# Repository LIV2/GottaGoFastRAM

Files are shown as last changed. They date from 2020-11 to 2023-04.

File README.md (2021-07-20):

# GottaGoFastRAM 8MB Autoconfig Fast RAM

This is an 8MB Autoconfig Fast RAM for Amiga 500/1000/2000/CDTV based on mkl's mem68k  
It's small size allows it to be stacked on top of an ide68k board  
Rather than use the original mem68k Abel code I have written a new memory controller in Verilog

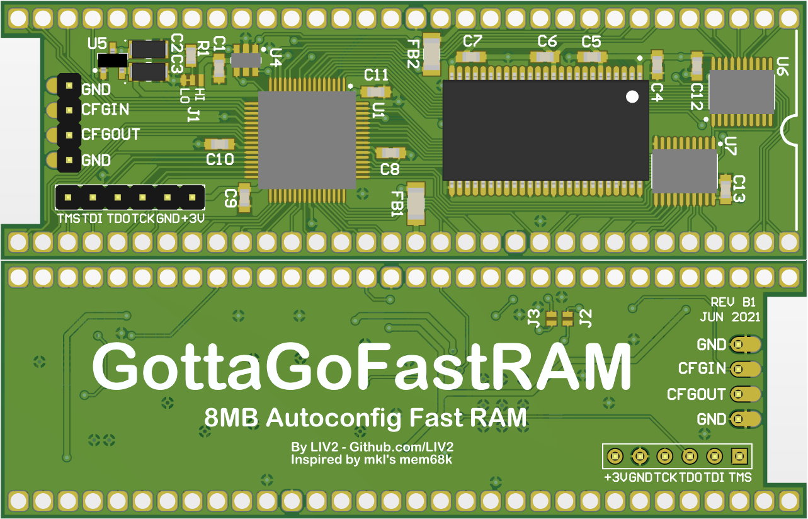
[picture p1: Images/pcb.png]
PCB

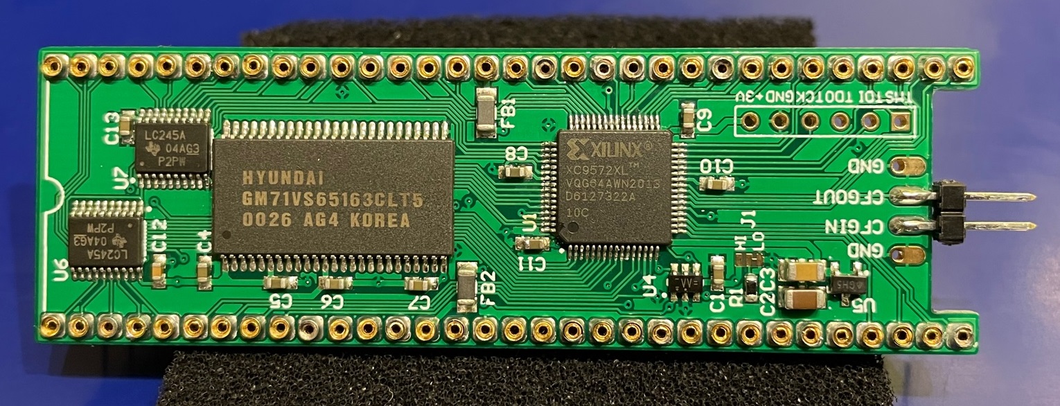
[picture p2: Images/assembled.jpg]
Assembled

## Table of contents
1. [PCB Ordering](#ordering-pcbs)
2. [Mounting Options](#mounting-options)
3. [Cfgin/out](#cfginout)
4. [Jumpers](#jumpers)
5. [CDTV](#cdtv)
6. [Timing Diagrams](#timing-diagrams)
7. [Bill of materials](#bill-of-materials)
8. [Known Issues](#known-issues)
9. [Experimental firmware](#experimental-firmware)

## Ordering PCBs
I recommend ordering the PCB with a 0.6 or 0.8mm thickness if you intend on stacking with an ide68k or mouting using a DIP socket/machined pin strips.  
If you are going to mount using the socket pins and not stacking with an ide68k I'd recommend going with the usual 1.6mm to reduce flexing.

## Mounting options

1. Can be soldered to the bottom of a machined pin socket/machined pin strips (will require some cutting of the dip socket to fit the caps/ferrites near the plastic)  
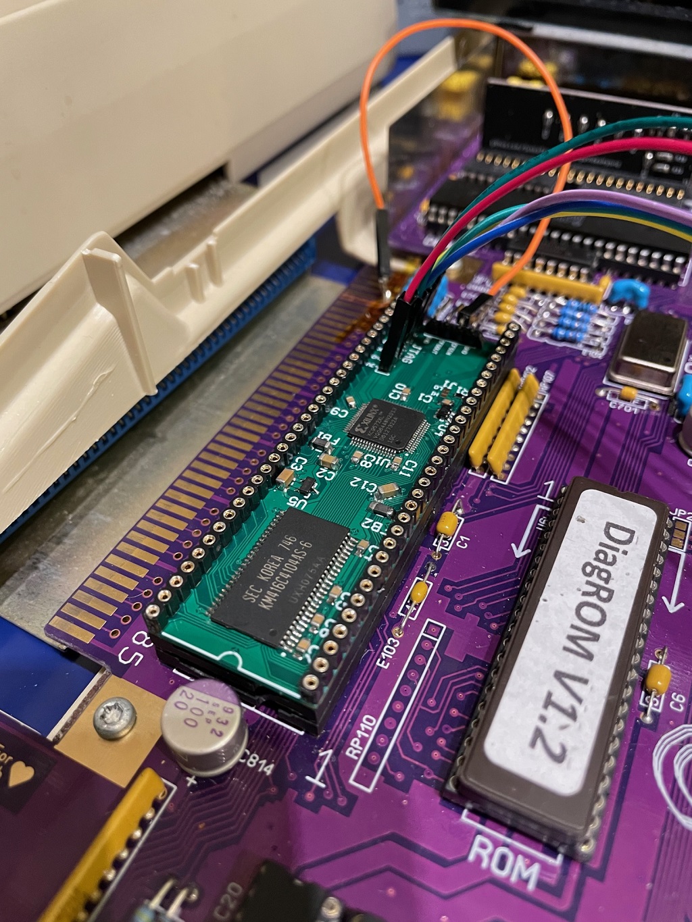
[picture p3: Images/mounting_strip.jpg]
  
2. Can be soldered to socket pins and stacked with an ide68k  
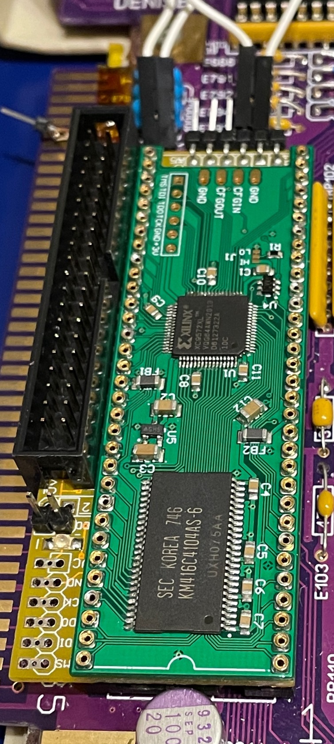
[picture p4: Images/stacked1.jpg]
  
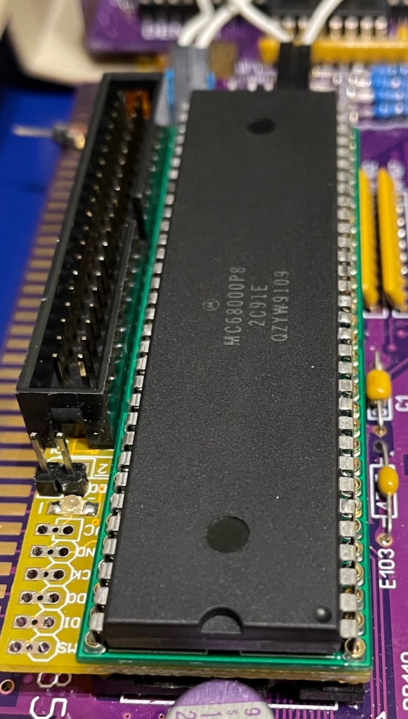
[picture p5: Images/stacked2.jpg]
  

## Cfgin/out
These pins allow you to insert the memory module into your autoconfig chain.  
If there are no other autoconfig devices in your system you can just leave these unconnected otherwise you will need to either connect CFGOut to the CFGin of the first device in your existing autoconfig chain, or connect CFGIn to the CFGOut pin of the last device in your existing autoconfig chain.  
In the Amiga 2000 you can connect CFGIN to U606 Pin 8 which will add the device to the end of the chain but __NOTE: This takes up the config signal for the leftmost slot (CN601) so do NOT install a Zorro card there__

You can also connect cfgin and cfgout with a jumper to disable the device temporarily

## Jumpers
J1: Cfgin pull up/down (You will probably want to leave this at default unless you know what you're doing)  
J2-3: Bridge these if you have not fitted the buffer U4

## CDTV
The CDTV's DMAC takes up the first autoconfig slot, so if you intend to use this with a CDTV use the CDTV specific .JED file to program the CPLD

If you have a Rev A or Rev B (not B1) board you will need to apply a [small mod for CDTV compatibility](https://github.com/LIV2/GottaGoFastRAM/issues/4/#issuecomment-868977723)

## Timing Diagrams
Read Cycle  
Write Cycle

### Bill of materials
|Component|Location|QTY|Link|Remarks|
|---|---|---|---|---|
|4Mx16 3V DRAM TSSOP - K4E641612D or GM71VS65163 |U3|1|-|eBay/Aliexpress etc.|
|XC9572XL-10VQ64C|U1|1|[Mouser](https://www.mouser.se/ProductDetail/217-C9572XL-10VQG64C)<br />[DigiKey](https://www.digikey.com/short/2f7qn38b)||
|74LVC2G17 TSSOP-6/SOT-363|U4|1|[Mouser](https://www.mouser.com/ProductDetail/771-74LVC2G17GVQ100H)<br />[DigiKey](https://www.digikey.com/short/95mn57tt) ||
|AP2210N-3.3 SOT-23|U5|1|[Mouser](https://www.mouser.com/ProductDetail/621-AP2210N-3.3TRG1)<br />[DigiKey](https://www.digikey.com/short/30rd0zn5)|Maybe can be substituted with MCP1703AT-3302E|
|74LVC245N TSSOP|U6,U7|2|[Mouser](https://www.mouser.com/ProductDetail/595-SN74LVC245APWRG4)<br />[DigiKey](https://www.digikey.com/short/pnq3wff3)|Can be substituted with SN74LVTH245 or SN74LVCR2245|
|Ferrite Bead, 1206 package|FB1, FB2|2|[Mouser](https://www.mouser.com/ProductDetail/875-MI1206K601R-10)<br />[DigiKey](https://www.digikey.com/short/n4p04ctv)|Can be substituted with 0 Ohm 1206 resistors|
|10K Resistor, 0603|R1|1|[Mouser](https://www.mouser.com/ProductDetail/603-RT0603FRD0710KL)<br />[DigiKey](https://www.digikey.com/short/nvvrt5dw)||
|0.1uF Ceramic Capacitor, 0603|C1,4-13|11|[Mouser](https://www.mouser.com/ProductDetail/80-C603C104K5RAC3121)<br />[DigiKey](https://www.digikey.com/short/f7trtfwt)||
|4.7uF Ceramic Capacitor, 1206|C2|1|[Mouser](https://www.mouser.com/ProductDetail/187-CL31B475KAHNFNE)<br />[DigiKey](https://www.digikey.com/short/d7mbf5nn)||
|10uF Ceramic Capacitor, 1206|C3|1|[Mouser](https://www.mouser.com/ProductDetail/187-CL31A106MAHNNNE)<br />[DigiKey](https://www.digikey.com/short/rqt1br0q)||
|Socket pins|Pins|64|[Aliexpress](https://www.aliexpress.com/item/32791545218.html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,searchweb201602_,searchweb201603_)|Use these if stacking with an ide68k module|
|64-Pin DIP socket - machined pin|Pins|1|[Mouser](https://www.mouser.com/ProductDetail/575-193964)|If not stacking with ide68k - pcb can be soldered to bottom of this flush with the plastic|

## Known issues
1. Rev A & B - Incorrect voltage supplied to U4 causes incompatibility with CDTV. Fixed in Rev B1 but you can [rework Rev A or B boards by following the instructions here](https://github.com/LIV2/GottaGoFastRAM/issues/4/#issuecomment-868977723)

## Experimental Firmware
* [AutoSnoop Firmware - Autoconfig after all other Z2 devices without any wires](https://github.com/LIV2/GottaGoFastRAM/tree/snoopy)

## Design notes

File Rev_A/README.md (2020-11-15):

# GottaGoFastRAM 8MB Autoconfig Fast RAM

This is an 8MB Autoconfig Fast RAM for Amiga 500/1000/2000/CDTV based on mkl's mem68k  
It's small size allows it to be stacked on top of an ide68k board  
Rather than use the original mem68k Abel code I have written a new memory controller in Verilog

Unfortunately the memory modules are hard to find, I was able to get some by scouring eBay for some 16/32MB simms and looking for ones pictured with the right ram modules - If you see a 16/32MB simm with 2/4 50-pin TSSOP modules then they're probably the right ones

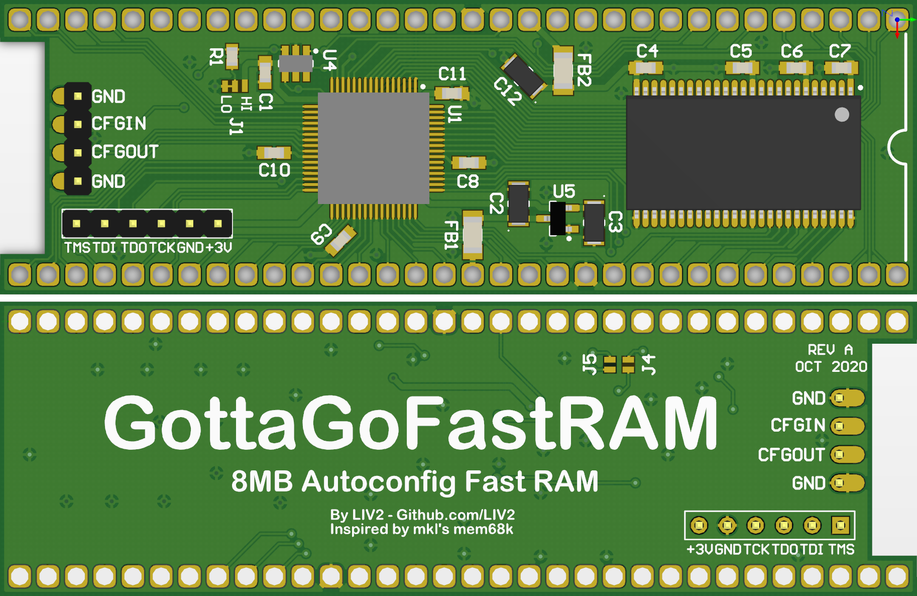
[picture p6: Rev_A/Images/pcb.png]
PCB


## PCB Ordering
I recommend ordering the PCB with a 0.6 or 0.8mm thickness if you intend on stacking with an ide68k or mouting using a DIP socket/machined pin strips.  
If you are going to mount using the socket pins and not stacking with an ide68k I'd recommend going with the usual 1.6mm to reduce flexing.

## Mounting options

1. Can be soldered to the bottom of a machined pin socket/machined pin strips (will require some cutting of the dip socket to fit the caps/ferrites near the plastic)
2. Can be soldered to socket pins and stacked with an ide68k

## Cfgin/out
These pins allow you to insert the memory module into your autoconfig chain.  
If there are no other autoconfig devices in your system you can just leave these unconnected otherwise you will need to either connect CFGOut to the CFGin of the first device in your existing autoconfig chain, or connect CFGIn to the CFGOut pin of the last device in your existing autoconfig chain.  
You can also connect cfgin and cfgout with a jumper to disable the device temporarily

## Jumpers
J1: Cfgin pull up/down (You will probably want to leave this at default unless you know what you're doing)
J2-3: Bridge these if you have not fitted the buffer U4

## CDTV
The CDTV's DMAC takes up the first autoconfig slot, so if you intend to use this with a CDTV use the CDTV specific .JED file to program the CPLD

## Timing Diagrams
Read Cycle  
Write Cycle

### Bill of materials
|Component|Location|QTY|Link|Remarks|
|---|---|---|---|---|
|4Mx16 5V DRAM - KM416C4100|U3|1|-|Look for 16MB SIMMs on eBay which show only 2 tssop package RAMs|
|XC9572XL-10VQ64C|U1|1|[Mouser](https://www.mouser.se/ProductDetail/217-C9572XL-10VQG64C)||
|74LVC2G17|U4|1|[Mouser](https://www.mouser.com/ProductDetail/771-74LVC2G17GVQ100H)||
|AP2210N-3.3|U5|1|[Mouser](https://www.mouser.com/ProductDetail/621-AP2210N-3.3TRG1)||
|Ferrite Bead, 1206 package|FB1, FB2|2|[Mouser](https://www.mouser.com/ProductDetail/875-MI1206K601R-10)||
|0.1uF Ceramic Capacitor, 0603|C1,4-11|9|[Mouser](https://www.mouser.com/ProductDetail/80-C603C104K5RAC3121)||
|4.7uF Ceramic Capacitor, 1206|C2,C12|2|[Mouser](https://www.mouser.com/ProductDetail/791-1206X475K160CT)||
|10uF Ceramic Capacitor, 1206|C3|1|[Mouser](https://www.mouser.com/ProductDetail/80-C1206C106K4R)||
|Socket pins|Pins|64|[Aliexpress](https://www.aliexpress.com/item/32791545218.html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,searchweb201602_,searchweb201603_)|Use these if stacking with an ide68k module|
|64-Pin DIP socket - machined pin|Pins|1|[Mouser](https://www.mouser.com/ProductDetail/575-193964)|If not stacking with ide68k - pcb can be soldered to bottom of this flush with the plastic|

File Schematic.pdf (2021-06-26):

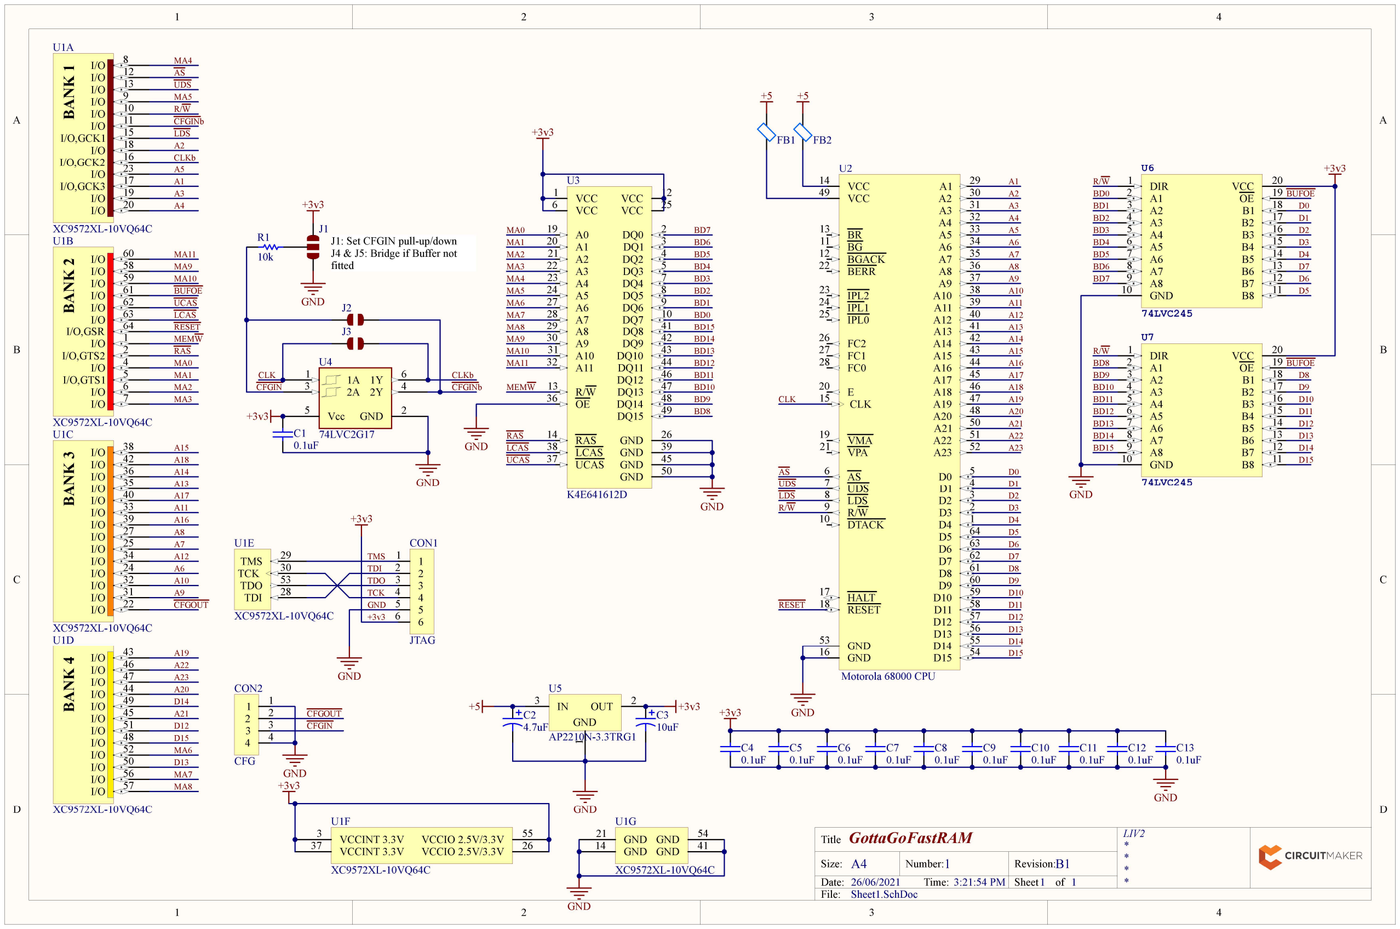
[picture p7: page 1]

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
LIV2
*
*
*
1 *

## GottaGoFastRAM

### 1 B1

26/06/2021 | 3:21:54 PM
Sheet1.SchDoc

Title

Size: | Number:
Date:
File:

Revision:
Time: | Sheet | of

A4

VCC 1

DQ0 | 2
DQ1 | 3
DQ2 | 4
DQ3 | 5

VCC 6

DQ4 | 7
DQ5 | 8
DQ6 | 9
DQ7 | 10
VCC | 12

R/W 13

RAS 14

A0 19
A1 20
A2 21
A3 22
A4 23
A5 24
VCC | 25
GND | 26

A6 27
A7 28
A8 29
A9 30
A10 31
A11 32

OE 36

UCAS 37 | LCAS 38 | GND | 39
DQ8 | 41
DQ9 | 42
DQ10 | 43
DQ11 | 44
GND | 45
DQ12 | 46
DQ13 | 47
DQ14 | 48
DQ15 | 49
GND | 50

U3

K4E641612D

D4 | 1
D3 | 2
D2 | 3
D1 | 4
D0 | 5 AS 6
UDS 7
LDS 8
R/W 9
DTACK 10

BG 11
BGACK 12

BR 13

VCC 14

CLK 15

GND 16

HALT 17
RESET 18

VMA 19

E

20

VPA 21

BERR 22

IPL2 23
IPL1 24
IPL0 25

FC2 26
FC1 27
FC0 28
A1 | 29
A2 | 30
A3 | 31
A4 | 32
A5 | 33
A6 | 34
A7 | 35
A8 | 36
A9 | 37
A10 | 38
A11 | 39
A12 | 40
A13 | 41
A14 | 42
A15 | 43
A16 | 44
A17 | 45
A18 | 46
A19 | 47
A20 | 48

VCC 49

A21 | 50
A22 | 51
A23 | 52

GND 53

D15 | 54 D14 | 55 D13 | 56 D12 | 57 D11 | 58 D10 | 59 D9 | 60 D8 | 61 D7 | 62 D6 | 63 D5 | 64

U2

Motorola 68000 CPU

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
RESET

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
MA10
MA11

+3v3

GND

MEMW

RAS
LCAS
UCAS BANK ¹I/O | 8
I/O | 12
I/O | 13
I/O | 9
I/O | 10
I/O | 11
I/O,GCK1 | 15
I/O | 18
I/O,GCK2 | 16
I/O | 23
I/O,GCK3 | 17
I/O | 19
I/O | 20

U1A

XC9572XL-10VQ64C BANK ²I/O | 60
I/O | 58
I/O | 59
I/O | 61
I/O | 62
I/O | 63
I/O,GSR | 64
I/O | 1
I/O,GTS2 | 2
I/O | 4
I/O,GTS1 | 5
I/O | 6
I/O | 7

U1B

XC9572XL-10VQ64C BANK ³I/O | 38
I/O | 42
I/O | 36
I/O | 35
I/O | 40
I/O | 33
I/O | 39
I/O | 27
I/O | 25
I/O | 34
I/O | 24
I/O | 32
I/O | 31
I/O | 22

U1C

XC9572XL-10VQ64C BANK ⁴I/O | 43
I/O | 46
I/O | 47
I/O | 44
I/O | 49
I/O | 45
I/O | 51
I/O | 48
I/O | 52
I/O | 50
I/O | 56
I/O | 57

U1D

XC9572XL-10VQ64C

TCK | | 30
TDI | 28 TDO | 53
TMS | | 29

U1E

XC9572XL-10VQ64C

VCCINT 3.3V 3

VCCINT 3.3V 37 | VCCIO 2.5V/3.3V | 26 VCCIO 2.5V/3.3V | 55

U1F

XC9572XL-10VQ64C

GND 14 | GND 21
GND | 41 GND | 54

U1G

XC9572XL-10VQ64C

MEMW
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
MA10

MA11

R/W
CFGINb

AS
UDS

LDS

CLKb

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
BUFOE
UCAS
LCAS
RESET

CFGOUT

+3v3

GND

IN 3 | 1
OUT | 2

GND

U5

AP2210N-3.3TRG1

GND

+5 | +3v3

+5

C2
4.7uF

C3
10uF
C4
0.1uF

C5
0.1uF

C6
0.1uF

C7
0.1uF

C8
0.1uF

C9
0.1uF

C10
0.1uF

C11
0.1uF

GND

+3v3 1

1
2

2
3

3
4

4

CON2

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
CON1

JTAG

GND

+3v3

TMS
TDI
TDO
TCK
GND
+3v3

GND

CFGIN

CFGOUT

1A 1

GND 2

2A 3

2Y 4

Vcc 5

1Y 6

U4

C1 74LVC2G17
0.1uF

GND

CLK | CLKb
CFGIN | CFGINb

J1

GND

R1
10k

FB1 FB2

J2

J3

J1: Set CFGIN pull-up/down J4 & J5: Bridge if Buffer not fitted

GND

R/W

R/W

BUFOE

BUFOE

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
BD10
BD11
BD12
BD13
BD14
BD15

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
BD10

BD11

BD12

BD13

BD14

BD15

DIR 1
A1 2
A2 3
A3 4
A4 5
A5 6
A6 7
A7 8
A8 9
GND 10 | B8 | 11 B7 | 12 B6 | 13 B5 | 14 B4 | 15 B3 | 16 B2 | 17 B1 | 18 OE | 19 VCC | 20

U6

74LVC245

DIR 1
A1 2
A2 3
A3 4
A4 5
A5 6
A6 7
A7 8
A8 9
GND 10 | B8 | 11 B7 | 12 B6 | 13 B5 | 14 B4 | 15 B3 | 16 B2 | 17 B1 | 18 OE | 19 VCC | 20

U7

74LVC245
GND

+3v3

C12
0.1uF

C13
0.1uF

+3v3

+3v3

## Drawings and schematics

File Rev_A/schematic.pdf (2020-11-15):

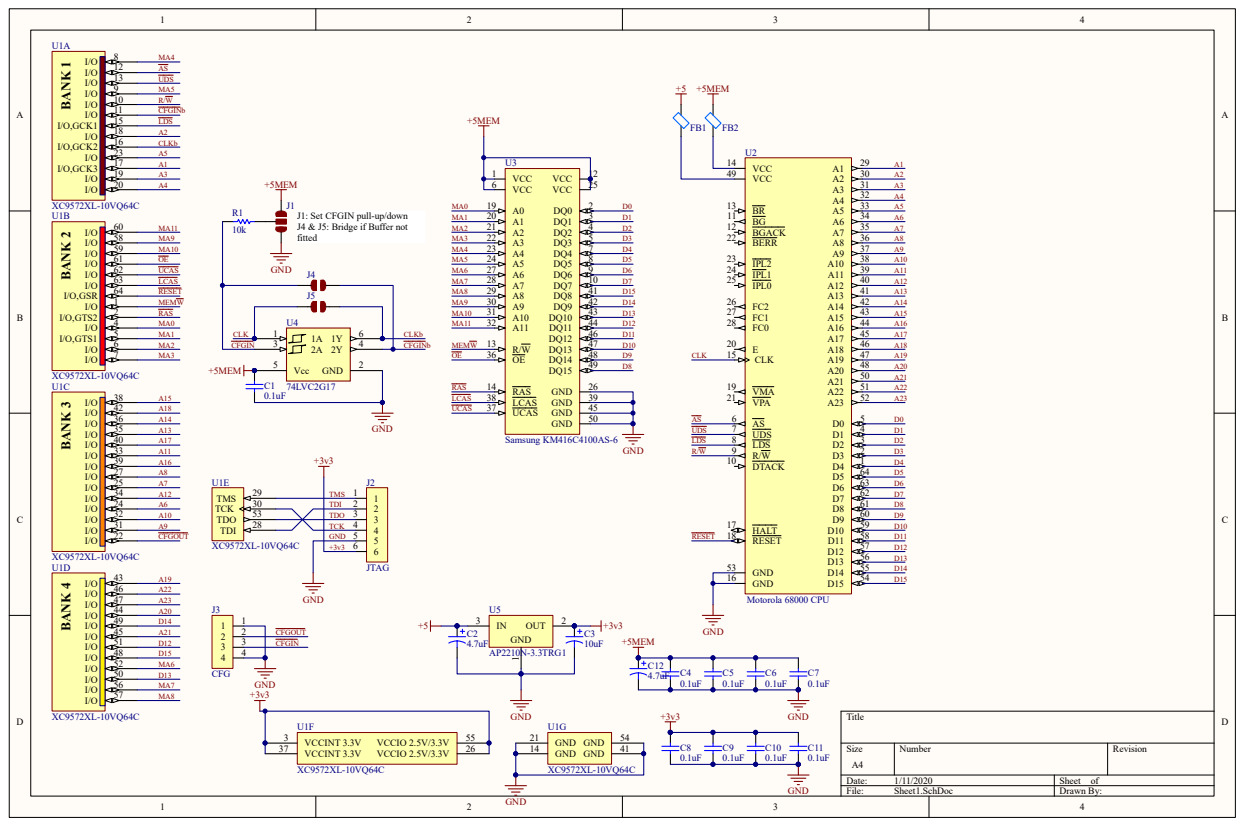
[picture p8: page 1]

J1: Set CFGIN pull-up/down
J4 & J5: Bridge if Buffer not
fitted

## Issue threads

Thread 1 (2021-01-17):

Magenta error color?!?

pazuzu72, 2021-01-17:
I made this expansion for my Amiga 1000 and I must say it works perfectly without any problems. The only weird thing I noticed is that on power up, before the kickstart screen, the color is magenta (?) where it was gray before.

LIV2, 2021-01-18:
Hi @pazuzu72

Weird! I think maybe it's because I made a mistake that caused the buffers to enable during reset which might have been causing your magenta screen.

I've attached an updated .jed file which should correct this mistake and hopefully fix your magenta screen: [gottagofast.zip](https://github.com/LIV2/GottaGoFastRAM/files/5827831/gottagofast.zip)

I hope that fixes it!

pazuzu72, 2021-01-18:
Thanks. I'll try it later. I will post the result of the update.

LIV2, 2021-02-11:
@pazuzu72 Did this solve your issue?

pazuzu72, 2021-02-11:
Unfortunately I didn't have time due to work. I hope this weekend to succeed. It will be my pleasure to post the result.

pazuzu72, 2021-02-12:
All right. The magenta is gone !! Thanks so much :-)

LIV2, 2021-02-13:
Awesome, glad I could help!

Closed 2021-02-13.

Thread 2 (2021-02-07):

schematic pdf

kipper2k, 2021-02-07:
Hi,  Great design, i like the 1x8MB ram chip.  I have made a A500 IDE board with CF header and would like to add this fastmem design to it, Do you have  a schematic pdf available for sharing or eagle cad files ?

Thanks.  Brian.

LIV2, 2021-02-07:
Hi Brian,

Thanks, this board was designed with Altium CircuitMaker but the schematics are available here: https://github.com/LIV2/GottaGoFastRAM/blob/master/Schematic.pdf

Do you have a link to your project? It sounds good I'd love to get my hands on one when it is released :)

Closed 2021-03-18.

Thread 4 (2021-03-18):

Doesn't work in CDTV

LIV2, 2021-03-18:
Need to acquire a CDTV to find out why

nobodyisinocent, 2021-06-02:
Hello,
I confirm that the jed file for the CDTV doesn't work.
You said that you don't own a CDTV, but if you want I can test new jed files if you want since I have a CDTV and a GottaGOFastRAM ! No problem for me.
Kind regards,
Franck

LIV2, 2021-06-03:
Hi @nobodyisinocent
That would be great! I will try to have an educated guess as to what the problem could be and return with some JED files to test

nobodyisinocent, 2021-06-03:
Hi Liv !
Great news ! I'll wait for your new JED to make tests !
Perhaps you could also look at the 4MB SRAM of the TK30 designed by Mattze from a1k.org.
He had made a specific JED file for his board. It's not the same design but perhaps that could help you ?
Kind regards,
Franck

LIV2, 2021-06-03:
I've tweaked a few things based on learnings from the GottaGoFastRAM2000 board which I am hoping will help, Can you please try out the attached jed file when you have the time and let me know? Thanks for the idea I will check out that project too
[ggfcdtvtest1.zip](https://github.com/LIV2/GottaGoFastRAM/files/6590549/ggfcdtvtest1.zip)

nobodyisinocent, 2021-06-03:
Hi !

New jed file injected into the XC and tested. Actually I obtain the same issue.

I realized I didn't explain what's happening why the CDTV is switched on.
1- The CDTV displays a black screen. The CD-ROM is initialized during this step,
2- A a faded yellow screen is displayed just after during a few seconds,
3- A reset is automatically done,
4- And we go back to the step 1.

I tested also with a floppy drive connected to see if I could hear the click of the drive. Nothing !

Kind regards,
Franck

LIV2, 2021-06-03:
Strange...

Does your board work in an A500?

If possible can remove the board and boot up Sysinfo and see how many boards are listed under the "Boards" option?

LIV2, 2021-06-03:
Also can you try the attached firmware? this one doesn't use autoconfig it just forces the memory to map so it can be tested with AmigaTestKit by choosing the option to detect memory, you should be able to detect 8MB and then test it all which will tell us if the part that is broken is related to autoconfig or related to the memory control

[gottagofastnoautoconf.zip](https://github.com/LIV2/GottaGoFastRAM/files/6593253/gottagofastnoautoconf.zip)

LIV2, 2021-06-03:
And another autoconfig one to test when you get a second please :)

[gottagofastcdtvtest3.zip](https://github.com/LIV2/GottaGoFastRAM/files/6593328/gottagofastcdtvtest3.zip)

nobodyisinocent, 2021-06-03:
Initially, the board worked onto the A500. I'm going to inject the firmware for the A500 if everything is good.
After, I'll test the two firmwares you sent today.

One question, For the CDTV, is there another signal which is needed to be picked up ?
I read something about CFGOut and CFGin. One of them is needed since there is an autoconfig device on the CDTV (DMAC) ?

LIV2, 2021-06-04:
In the CDTV the dmac's cfgin is tied to ground but it does have a CFGOUT by the looks of it but this doesn't appear to be easily accessible - only connected to the diagnostic port

The firmwares for various CDTV fast ram boards (incl my CDTV fw) work around this by watching the bus and wait until after they see the DMAC being configured before they respond to autoconfig requests.

I have tested that this part works with an A500 & A590 setup which has the same DMAC

nobodyisinocent, 2021-06-04:
Hi !

Thanks for the information about the GFG signals.

About my RAM board, I have put the A500 firmware into the cpld. On the A500, I obtain a red screen.
The GottaGoFastRAM is installed onto a IDE68K. So, I have removed the /OVR and /INT2 connector. And in this configuration, the A500 displayed directly the early boot menu on the device menu. The RAM is shown as defective. I don't understand why since this board worked fine before onto my A500.
I put the no-auto-config firmware, and the A500 booted fine onto the IDE68K.

Anyway, I had an another IDE68K + GottaGoFastRAM onto this A500. So, I have injected the first firmware you sent me to test if the result would be the same. And yes, the result is the same with yellow screen.
So, I have injected again the A500 firmware to verify the integrity of the board ram. And yes, it always works perfectly.

I have finally injected the no-Auto-config firmware to test into the cpld. Tested onto my CDTV, it boots perfectly onto the CF card of the IDE68K. This evening, I'll test to add the memory manually with the "addmen" command line.

And after, I'll test the third firmware you've sent !

LIV2, 2021-06-04:
Hmm the "Defective" screen usually means that kickstart did a memory test and found the ram to be faulty - perhaps a bad solder joint or something? It should work fine with the IDE68K I have a few here stacked with this ram board.

Better than addmem is booting [AmigaTestKit](https://github.com/keirf/Amiga-Stuff/releases) if you have a Gotek or something - this allows you to autodetect memory and test it.

Thanks so much for your help!

nobodyisinocent, 2021-06-04:
Yes, it worked before. But yes, I suspect faulty ram. I'll check the soldering.

Yes, I have downloaded AmigaTestKit also, and I'll used it. :-)

No problem. It's a pleasure, I like your little board !

nobodyisinocent, 2021-06-05:
Hi,

I have tried to test the RAM on my CDTV. AmigaTest Kit refused to run. The menu wasn't available...
I tried onto an A500+, and there, it has run fine. The 8MB were found.

So, I have tested again onto my CDTV with the CDROM part disabled thanks to the JP15 jumper which have to be opened in that case. Like that, I obtain a pure A500. In this configuration, AmigaTestKit run fine, but the test is not successful. Only 3.5MB are found as you can see on the picture.
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

Presently, My CDTV is equipped with the 2.30 Extended ROMs. I'll test with the original ones, but I have to take a look at the jumpers. I'm sure I have modified one of them to use the 2.30 ROMs, but I don't remember which one !

nobodyisinocent, 2021-06-05:
For information, if I use AddMem 200000 9FFFFF, the command line returns an error which says that only a part of memory is found and the Fast RAM is not activated.
I'll note the exact error message.

LIV2, 2021-06-06:
Well that is very strange, I get the feeling there is some problem with the design. perhaps the buffers don't work well with the CDTV for some reason (noise immunity or something?)

I've bought a CDTV on eBay now so I can poke around with my oscilloscope etc, thanks so much for your help I'll keep this thread updated with my findings

nobodyisinocent, 2021-06-06:
Hi,

Great news ! Will be easier to find the problem.
For information, I have tested the 68030/4MB accelerator board from Matze.
The memory part of the accelerator board uses the A500 jed.
For that, I have disabled the CD-ROM part (with jumper JP15 opened). Like that, no DMAC initialization.
And the board run fine as shown into the pictures below.
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

nobodyisinocent, 2021-06-06:
Okay ! Thanks a lot for your great work ! :-)

LIV2, 2021-06-26:
Hi @nobodyisinocent

I received my CDTV earlier this week and have figured out the problem.
I made a mistake in the design by supplying the clock buffer with 5V instead of 3.3V which causes it to have the wrong threshold voltage for the clock when installed in a CDTV (but works fine on other amigas for some reason)

Yellow is the clock from the CDTV, blue is the buffered clock signal. ignore the difference between before/after for the yellow trace the amplitude is different because I didn't have a solid probe connection - only the buffered trace is interesting

## Before fix: the resulting clock output has too narrow a pulse that is late which causes the ram controller to not function correctly and misbehave
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

## After fix: nice square clock
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

## The fix:
You can fix this on a Rev B board in one of two ways:
1. Cut the relevant power trace at the right place and solder a jumper wire between the positive sides of C1 and C3 (recommended)
2. Remove U4 and solder the two jumpers closed on the bottom of the board

The buffer serves a useful purpose of cleaning the clock signal if there is noise or too slow rise time so I recommend doing option 1 as follows:
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

Make sure to reflash the CDTV specific firmware from the master branch rather than the testing ones I sent previously.

I'll update the documentation with this fix and also update the PCB design to fix this problem

nobodyisinocent, 2021-06-26:
Hi LIV !

It's a great news ! Perfect job. +1:
I'm going to make the mod onto my GottaGoFastRAM.
Mine is directly soldered onto an IDE68k board. I'll used the first recommended way.
I took a look at the schematic. For my configuration, if I cut the track between the via and C1 onto the top layer, that will be the same since HI position of J1 isn't closed. And as shown in your picture, I'll solder the wire between C3 & C1.

Fantastic ! My CDTV will have a 8MB board and an IDE port ! And it's thanks to you ! :-)
I'll say you as soon as it will be done.
Have a nice week-end.

LIV2, 2021-06-29:
Fantastic! Thanks so much for your help :)

MirekBie, 2022-12-20:
Hello. Can you tell me how to update the firmware for cdtv in GottaGoFastRam. what software and programmer to use?

LIV2, 2022-12-21:
@MirekBie you can program using a Raspberry Pi following the instructions here: https://linuxjedi.co.uk/2021/11/25/revisiting-xilinx-jtag-programming-from-a-raspberry-pi/ but you would replace FLASH_KICKSTART.jed at the xc3sprog command with the filename of the .jed you wish to program

Closed 2021-06-29.

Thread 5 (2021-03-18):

kipper2k cfide board variation

kipper2k, 2021-03-18:

kipper2k, 2021-03-18:
Hi, sorry i missed respoding in the other thread, i just tested my a508ide board, IDE works, there are quite a few jumpers on the underside where i forgot needed cpu signals, i will test the 8MB ram later tomorrow and if all good i will submit what should be final version. once good i will release

Closed 2023-10-19.

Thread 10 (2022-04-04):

Combination with A570 and "2MB RAM for A570"

StefanKrupop, 2022-04-04:
Dear LIV2,

thank you for this project! I built one and it seems to be working fine so far (just finished it).

I am using an A570 (together with a [Vector Falcon 570](http://amiga.resource.cx/expde/falcon570)) and tied CFGIN of the GottaGoFastRAM to Pin 11 on the A500 expansion connector, so it will get asserted after the DMAC in the A570 is configured. Seems to be ok, I see 2 MB Chip and 8 MB Fast.

However, I previously had a [2MB RAM for A570](http://amiga.resource.cx/expde/2mb570) expansion in the A570 as well, providing 2 MB of Fast RAM.
I now had to remove it to get the full 8 MB provided by the GottaGoFastRAM. With it installed the Amiga sees just 6 MB of Fast RAM.

I wonder whether it would be possible to use both expansions simultaneously, giving a total of 10 MB Fast RAM? The 2 MB RAM in the A570 seem to be mapped to 0x200000.

Kind regards,
Stefan

LIV2, 2022-04-04:
Hi Stefan,

Unfortunately it's not possible for this board to provide memory outside of the 8MB Autoconfig memory space as that would require the use of 2 more pins on the CPLD which is already maxed out. so it would not be possible to get 10MB this way.

To make it coexist better with the 570 Ram expansion you could try the [Experimental firmware](https://github.com/LIV2/GottaGoFastRAM/tree/snoopy/Binaries/experimental) which would allow the GGF board to completely fill up the remaining ram space giving you 8MB total fastram even with the 570 and it's 2MB expansion.
If you go down that path please let me know how it goes

StefanKrupop, 2022-04-04:
Thank you for the quick reply!

I would have thought that 8  MB AutoConfig would be fine, as the 2 MB are also AutoConfig'ed (at least I think that). Or does the A500 just have one 8 MB Autoconfig memory space that is shared between all expansions?

This is what the "Expansion Board Diagnostic" (Holding both mouse buttons on boot) shows for the different configurations:

GGF and A570, no 2 MB-Expansion:
| Board Number | Manufacturer | Product | Status |
| ------------ | ------------ | ------- | ------ |
| 1 | 514 | 3 | Working |
| 2 | 2011 | 69 | Working |

Gives Fastmem from 0x200000 to 0x9fffff.

A570 with 2 MB-Expansion, no GGF:
| Board Number | Manufacturer | Product | Status |
| ------------ | ------------ | ------- | ------ |
| 1 | 514 | 3 | Working |
| 2 | 514 | 10 | Working |

Gives Fastmem from 0x200000 to 0x3fffff.

GGF and A570 with 2 MB-Expansion:
| Board Number | Manufacturer | Product | Status |
| ------------ | ------------ | ------- | ------ |
| 1 | 514 | 3 | Working |
| 2 | 514 | 10 | Working |
| 3 | 2011 | 69 | Defective |
| 4 | 2011 | 69 | Working |

Gives Fastmem from 0x200000 to 0x3fffff and 0x600000 to 0x9fffff.

Shouldn't the Autoconfig process simply map the GGF behind the 2 MB of the A650, starting at 0x400000?

Kind regards,
Stefan

StefanKrupop, 2022-04-04:
Never mind. I found an address map for the A500 and indeed, just 0x200000 - 0x9fffff is reserved for Autoconfig, 0xa00000 - 0xbeffff is "reserved". So not more than 8 MB possible via Autoconfigured expansions...

LIV2, 2022-04-04:
> I would have thought that 8 MB AutoConfig would be fine, as the 2 MB are also AutoConfig'ed (at least I think that). Or does the A500 just have one 8 MB Autoconfig memory space that is shared between all expansions?

Yes Zorro expansions all share the 8MB Block of 0x200000 - 0x9FFFFF so the maximum amount of fast ram is 8MB

> Shouldn't the Autoconfig process simply map the GGF behind the 2 MB of the A650, starting at 0x400000?

Kickstart maps 2MB blocks on 2MB boundaries, 4MB on 4MB boundaries etc which is why this doesn't happen unfortunately - it probably would have complicated address decoding for boards back in the day I guess.

Due to kickstart bugs it is not usually possible for the board to 6MB with this autosizing trick, it can cause yellow screen errors.
The Experimental firmware though sniffs autoconfig cycles for other devices and resizes it's offering in 2MB chunks to match & fill up the remaining space, so this should give you the full 8MB even with the A570's 2MB installed

Closed 2022-04-04.

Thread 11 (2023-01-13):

No FastRAM detected A500 rev6a KS3.1.4

krug3rf, 2023-01-13:
Hi everyone and happy new year ^^

I build the last rev of the PCB with the revb firmware.
The A500 (with 1MB on the motherboard, not an extension) start but the FastRAM stuck at 0MB (AmigaTestKit, Diagrom, etc.)

What I tested, but no effect ;(

- replace the Xilinx (twice),
- replace the DRAM TSSOP twice (_samsung K4E641612D in my case_),
- remove the additional 512kb,
- replace the KS by an 1.3

Are you aware about this kind of issue  ?

LIV2, 2023-01-13:
Hi,

This should work with your system and has been tested in a rev6a but I'm not yet sure why it doesn't work for you.

Can you please take a photo of the PCB and attach it to this issue?

krug3rf, 2023-01-13:
I just finish a last check, but stuck with 0MB

- reflow U6 and U7
- test on another rev6a
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

krug3rf, 2023-01-13:
And the impact.log
[_impact.log](https://github.com/LIV2/GottaGoFastRAM/files/10415924/_impact.log)

LIV2, 2023-01-13:
It looks like the solder joint of U4 pin 1 might be bad, if you haven't already reflowed that chip please do so.

If you have an oscilloscope you will want to probe pin 1 and 6 of U4 where you should see a 7Mhz clock signal on both pins, if this isn't working it would explain what you're experiencing.

If U4 is bad you can remove it and close the 2 solder jumpers on the bottom to bypass it, the board may be more reliable with U4 fitted though

krug3rf, 2023-01-14:
Thx for advise, I don't have an oscilloscope, so...

_"If U4 is bad you can remove it and close the 2 solder jumpers on the bottom to bypass it, the board may be more reliable with U4 fitted though"_

Do you talking about J2 and J3 ?

LIV2, 2023-01-14:
Yep those are the ones you will want to close.

krug3rf, 2023-01-14:
After two reflow on U4, bazinga !
Thx for your help !
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

Closed 2023-01-15.

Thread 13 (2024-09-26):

Micron MT4LC4M16R6

RetepV, 2024-09-26:
According to the datasheet, the Micron MT4LC4M16R6 ram chip could also be used.

Did anyone try that?

Note that there are 2 versions of the MT4LC4M16: MT4LC4M16**R6** is 4Mx16 with 4096 bytes refresh cycle, and the MT4LC4M16**N3** with 8192 bytes refresh cycle. I would bet that the N3 version will not work without changes to the CPLD firmware, so make sure to get the right **R6** version.

LIV2, 2024-09-26:
I believe that just about any 3.3v DRAM with a geometry of 4096x1024 should work

Where can these be purchased? I also dislike having to purchase ICs from Aliexpress or eBay

RetepV, 2024-10-02:
Hi LIV2, so for the past days, I have been looking around for suppliers of these kind of ram chips, but they are very thinly spread. The ram chips themselves are obsolete and no longer manufactured, I think. I found one supplier that's a normal webshop:

https://www.westfloridacomponents.com/IC681APH02/MT4LC4M16R6-5F+4M+x+16+EDO+DRAM+CMOS+Memory+IC+Micron.html

But I think the cheapest option is to search EBay for "32MB edo ram". EBay will return a huge list of results. And then scroll through the list to find 32MB simms with 2 ram chips on either side (not 4 on one side, they are . These most likely contain four of the 4Mx16 ram chips that we need.

Like this one: https://www.ebay.nl/itm/395007127367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

RetepV, 2024-10-02:
I compiled a small list of ram chips that we should be able to use:

* Hynix GM71VS65163
* Samsung K4E641612D
* Samsung KM416C4104B/C
* Micron MT4LC4M16R6
* Toshiba TC5165165BFT/BFTS

Be careful that many of these chips come in a 4096 or 8192 cycle refresh. We need the 4096 cycle version. The 4096 cycle version has 12 address bits A0..A11. The 8192 cycle versions have 13 address bits A0..A12. On the 4096 cycle rams, pin 33 is NC. On the 8192 cycle rams, pin 33 is A12.

This is about all of the information that I can give right now.

Of course, if you want to make these memory board in bulk, you should be able to buy NOS chips through e.g. [utsource](https://www.utsource.net/), or maybe find them with [octopart](https://octopart.com).

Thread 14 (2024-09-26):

5V or 3.3V ram?

RetepV, 2024-09-26:
I wanted to make some of these boards and was checking out the ram options. And then I noticed that some 4Mx16 rams have 5V VCC, while others have 3.3V VCC. Looking at the schematics, it seems the ram chip is fed with 5V VCC.

You are recommending K4E641612D or GM71VS65163, but these are both 3.3V parts as far as I can see. Also, the Micron MT4LC4M16R6 that I wrote about earlier is a 3.3V part.

In your 'assembled.jpg' image, I see a GM71VS65163CLT-5, which is a 3.3V part. But in your 'stacked1.jpg' image, I see that you used a KM416LC4104AS-6 chip, and that is a 5V part according to the datasheet.

Schematic.pdf for both revision A and B1 show that the ram is fed with 5V. But 5V would destroy a 3.3V ram, imo. So how are you handling that difference?

RetepV, 2024-09-26:
Oh crap, I read the schematics wrong. My fault! I see that the rams are actually fed with the 3.3V, so we need 3.3V rams.

I'll close this issue because it's still a warning that the KM416LC4104AS-6 is a 5V chip according to the datasheet. I can't imagine that it would work reliably when fed with 3.3V.

Cheers!

LIV2, 2024-09-26:
Yep on Rev A the RAM is a 5V part supplied with 5V - this was changed to a 3.3V part in Rev B because at the time it was cheaper and easier to get 3.3V parts

The stacked configuration is shown with a Rev A, I will have to make a note on the page about htat

RetepV, 2024-10-02:
👍

Closed 2024-09-26.

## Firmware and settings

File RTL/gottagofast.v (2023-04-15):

/*
GottaGoFastRAM - 8MB Autoconfig FastRAM for Amiga 500(+)/1000/2000/CDTV
Copyright 2020 Matthew Harlum

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
Inspired by mkl's mem68k
*/

`ifndef makedefines // The defines ignored if being built by Makefile
`define SERIAL 32'd421
`define PRODID 8'1

`define autoconfig  // If disabled RAM is always mapped to $200000-9FFFFF
//`define cdtv      // Uncomment to build CDTV compatible version
//`define Offer_6M  // If told to shutup when offering 8MB, offer up a 2MB and also 4MB block next (useful with an A590/2091)
`define rev_b
`endif

module gottagofast(
    input CLK,
    input RESETn,
    input CFGINn,
    input UDSn,
    input LDSn,
    input ASn,
    input RWn,
    inout [15:12] DBUS,
    input [23:1] ADDR,
    output reg [11:0] MADDR,
    output reg CFGOUTn,
    output RASn,
    output UCASn,
    output LCASn,
    output OEn,
    output MEMWn
    );

reg reset_delayed1;
reg reset;

// Memory controller

reg ram_cycle;
reg access_ras;
reg access_ucas;
reg access_lcas;
reg refresh_ras;
reg refresh_cas;
reg [7:0] addr_match;

`ifdef autoconfig
// Autoconfig
localparam [15:0] mfg_id  = 16'd5194;
localparam [7:0]  prod_id = 8'd1;
localparam [31:0] serial = `SERIAL;

wire autoconfig_cycle;
reg shutup = 0;
reg CFGINnr;
reg configured;
reg [2:0] autoconfig_state;
reg [3:0] data_out;

localparam Offer_8M = 3'b000,
// If offering 2MB + 4MB blocks you need to offer the 2MB block first
// This is because of a kickstart bug where the memory config overflows if there is already 2MB configured before another 4MB then 2MB is configured...
`ifdef Offer_6M
        Offer_2M = 3'b001,
        Offer_4M = 3'b010,
`else
        Offer_4M = 3'b001,
        Offer_2M = 3'b010,
`endif
        Offer_1M = 3'b011,
        SHUTUP   = 3'b100;

assign DBUS[15:12] = (RESETn & autoconfig_cycle & RWn & !ASn & !UDSn) ? data_out[3:0] : 'bZ;

`ifdef cdtv
reg cdtv_configured;

assign autoconfig_cycle = (ADDR[23:16] == 8'hE8) & !CFGINnr & !shutup & cdtv_configured;
`else
assign autoconfig_cycle = (ADDR[23:16] == 8'hE8) & !CFGINnr & !shutup;
`endif

`ifdef cdtv
// CDTV DMAC is first in chain.
// So we wait until it's configured before we talk
always @(negedge UDSn or negedge reset)
begin
    if (!reset) begin
      cdtv_configured <= 1'b0;
    end else begin
    if (ADDR[23:16] == 8'hE8 & ADDR[8:1] == 8'h24 & !ASn & !RWn) begin
      cdtv_configured <= 1'b1;
    end
  end
end
`endif

// Register Config in/out at end of bus cycle
always @(posedge ASn or negedge reset)
begin
  if (!reset) begin
    CFGOUTn <= 1'b1;
    CFGINnr <= 1'b1;
  end else begin
    CFGOUTn <= !shutup;
    CFGINnr <= CFGINn;
  end
end

// Offers an 8MB block first, if there's no space offer 4MB, 2MB then 1MB before giving up
always @(posedge CLK or negedge reset)
begin
  if (!reset) begin
    data_out <= 'bZ;
  end else if (autoconfig_cycle & RWn) begin
    case (ADDR[8:1])
      8'h00:   data_out <= 4'b1110;
      8'h01:
        case (autoconfig_state)
          Offer_8M: data_out <= 4'b0000;
          Offer_4M: data_out <= 4'b0111;
          Offer_2M: data_out <= 4'b0110;
          Offer_1M: data_out <= 4'b0101;
          default:  data_out <= 4'b0000;
        endcase
      8'h02:   data_out <= ~prod_id[7:4]; // Product number
      8'h03:   data_out <= ~prod_id[3:0]; // Product number
      8'h04:   data_out <= ~4'b1000;
      8'h05:   data_out <= ~4'b0000;
      8'h08:   data_out <= ~mfg_id[15:12]; // Manufacturer ID
      8'h09:   data_out <= ~mfg_id[11:8];  // Manufacturer ID
      8'h0A:   data_out <= ~mfg_id[7:4];   // Manufacturer ID
      8'h0B:   data_out <= ~mfg_id[3:0];   // Manufacturer ID
      8'h0C:   data_out <= ~serial[31:28]; // Serial number
      8'h0D:   data_out <= ~serial[27:24]; // Serial number
      8'h0E:   data_out <= ~serial[23:20]; // Serial number
      8'h0F:   data_out <= ~serial[19:16]; // Serial number
      8'h10:   data_out <= ~serial[15:12]; // Serial number
      8'h11:   data_out <= ~serial[11:8];  // Serial number
      8'h12:   data_out <= ~serial[7:4];   // Serial number
      8'h13:   data_out <= ~serial[3:0];   // Serial number
      8'h20:   data_out <= 4'b0;
      8'h21:   data_out <= 4'b0;
      default: data_out <= 4'hF;
    endcase
  end
end

always @(negedge UDSn or negedge reset)
begin
  if (!reset) begin
    configured <= 1'b0;
    shutup <= 1'b0;
    addr_match <= 8'b00000000;
    autoconfig_state <= Offer_8M;
  end else if (autoconfig_cycle & !ASn & !RWn) begin
    if (ADDR[8:1] == 8'h26) begin
      // We've been told to shut up (not enough memory space)
      // Try offering a smaller block
      if (autoconfig_state >= SHUTUP-1) begin
        // All options exhausted - time to shut up!
        shutup <= 1;
        autoconfig_state <= SHUTUP;
      end else begin
        // Offer the next smallest block
        autoconfig_state <= autoconfig_state + 1;
      end
    end
    else if (ADDR[8:1] == 8'h24) begin
      case (autoconfig_state)
        Offer_8M:
          begin
            addr_match <= 8'hFF;
            shutup     <= 1'b1;
          end
        Offer_4M:
          begin
            case(DBUS)
              4'h2:    addr_match <= (addr_match|8'b00001111);
              4'h4:    addr_match <= (addr_match|8'b00111100);
              4'h6:    addr_match <= (addr_match|8'b11110000);
            endcase
            shutup     <= 1'b1;
          end
        Offer_2M:
          begin
            case(DBUS)
              4'h2:    addr_match <= (addr_match|8'b00000011);
              4'h4:    addr_match <= (addr_match|8'b00001100);
              4'h6:    addr_match <= (addr_match|8'b00110000);
              4'h8:    addr_match <= (addr_match|8'b11000000);
            endcase
            `ifdef Offer_6M
            autoconfig_state <= Offer_4M;
            `else
            shutup     <= 1'b1;
            `endif
          end
        Offer_1M:
          begin
            case(DBUS)
              4'h2:    addr_match <= (addr_match|8'b00000001);
              4'h3:    addr_match <= (addr_match|8'b00000010);
              4'h4:    addr_match <= (addr_match|8'b00000100);
              4'h5:    addr_match <= (addr_match|8'b00001000);
              4'h6:    addr_match <= (addr_match|8'b00010000);
              4'h7:    addr_match <= (addr_match|8'b00100000);
              4'h8:    addr_match <= (addr_match|8'b01000000);
              4'h9:    addr_match <= (addr_match|8'b10000000);
            endcase
            shutup     <= 1'b1;
          end
        default:  addr_match <= 8'b0;
      endcase
      configured <= 1'b1;
    end
  end
end
`endif

// Memory controller

assign RASn  = !(access_ras | (refresh_ras & refresh_cas));
assign UCASn = !((access_ucas) | refresh_cas);
assign LCASn = !((access_lcas) | refresh_cas);
`ifdef rev_b  // On Rev B OEn drives the buffers
assign OEn   = !ram_cycle | ASn | !RESETn | (UDSn & LDSn);
`else
assign OEn   = !(RWn & access_ras);
`endif
assign MEMWn = RWn | (UDSn & LDSn);
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

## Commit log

2020-11-15 Initial Commit.
    [PCB1.GBL, PCB1.GBO, PCB1.GBP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]
2020-11-18 Release Rev B
    [PCB1.GBL, PCB1.GBO, PCB1.GBP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]
2021-02-13 Fixes after feedback from A2000 testing by GadgetUK164
    * A2000 + A2091 has issues, the 2091s ram has errors when we are also configured
    ** Register CFGIN at the end of a bus cycle
    ** Assert autoconfig_cycle earlier (by switching from registered to combinational logic) so that cycles can be referenced by rising/falling edge of UDSn rather than clock
    ** Reset value of ram_cycle corrected
    ** Buffers no longer activated during reset (caused by incorrect ram_cycle reset value) fixes #1
    ** Narrower buffer_oe to fix potential clashes with zorro buffers on A2000
    [gottagofast.v]
2021-06-26 Revision B1
    Fixup U4 Voltage threshold by switching to 3.3V - #4 Fixes CDTV Compatibility
    [PCB1.GBL, PCB1.GBO, PCB1.GBP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]
2021-07-20 Update BOM
    Where possible replace out of stock parts with new ones
    Select some cheaper passives
    Add DigiKey links
    Add notes on possible substitutes

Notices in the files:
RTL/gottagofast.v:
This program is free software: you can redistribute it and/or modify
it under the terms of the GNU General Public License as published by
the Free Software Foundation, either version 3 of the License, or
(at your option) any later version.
